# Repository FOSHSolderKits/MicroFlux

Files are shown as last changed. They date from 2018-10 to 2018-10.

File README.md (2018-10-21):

# MicroFlux
Like a microphone, but for magnetic flux.

Based on the idea of the [Elektrosluch](https://store.lom.audio/products/elektrosluch-3?variant=4542168268832).



## Explanation
The explanation of how the circuit works, is annotated in the [schematic](https://github.com/FOSHSolderKits/MicroFlux/blob/master/img/MicroFlux.pdf).

## Pictures
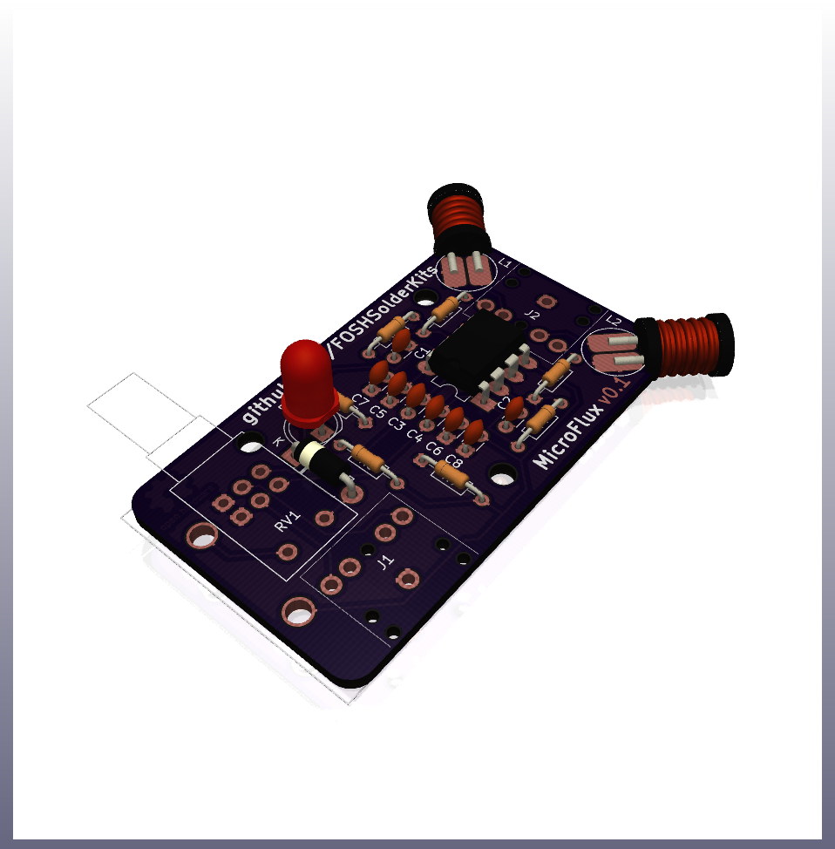
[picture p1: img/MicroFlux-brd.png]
3D render


board plot

schematic plot

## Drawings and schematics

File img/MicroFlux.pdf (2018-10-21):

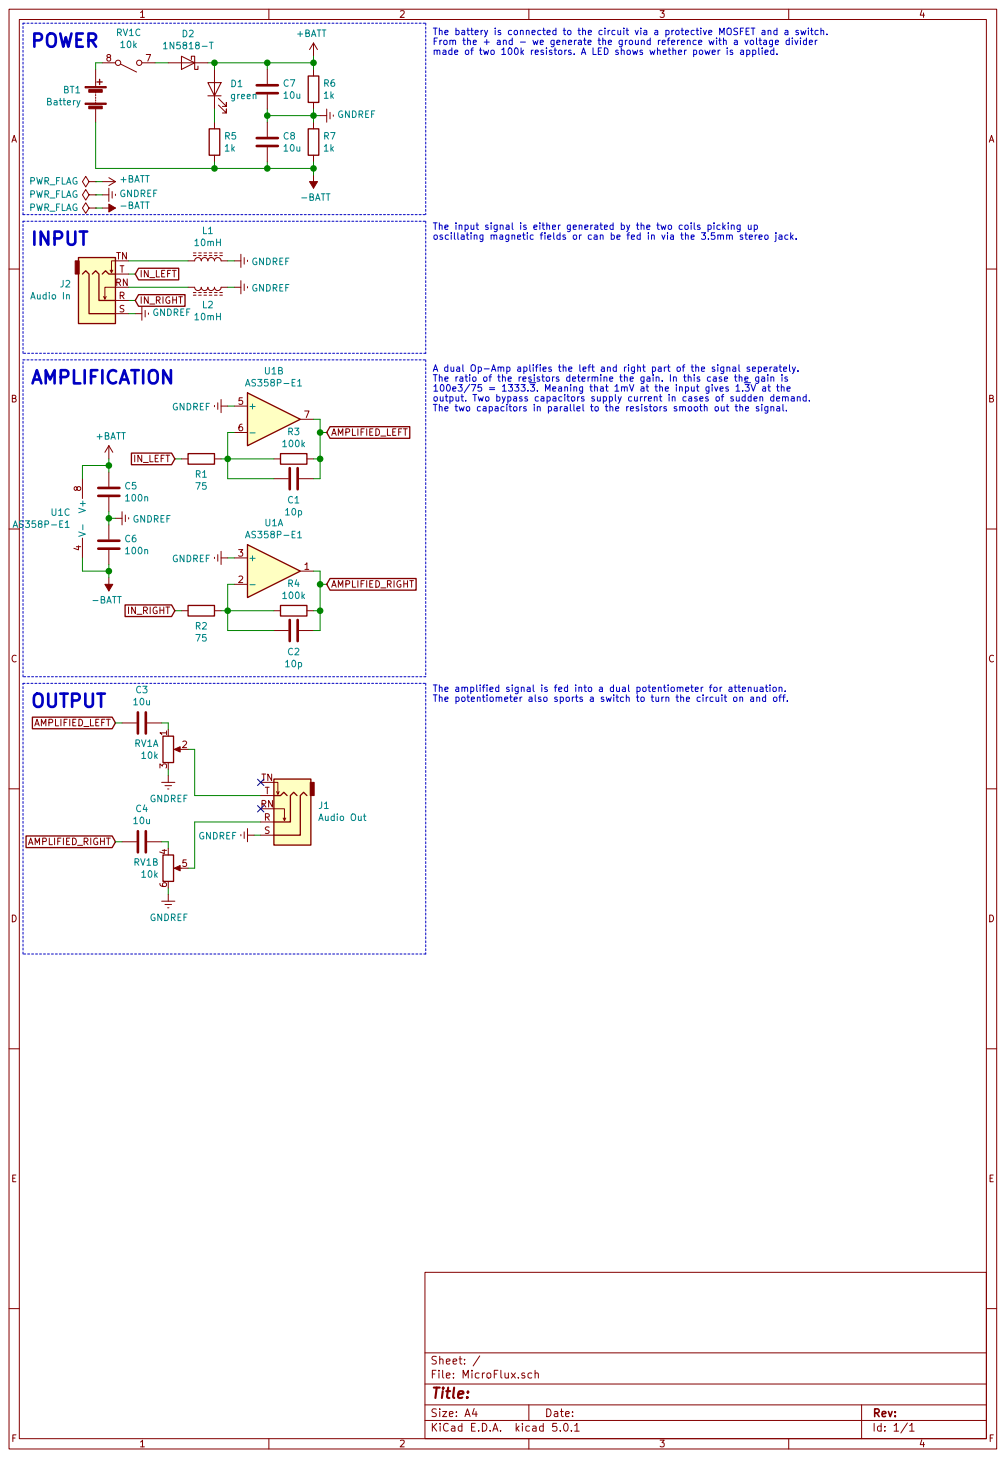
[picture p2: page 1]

The battery is connected to the circuit via a protective MOSFET and a switch.
From the + and - we generate the ground reference with a voltage divider
made of two 100k resistors. A LED shows whether power is applied.

The input signal is either generated by the two coils picking up

oscillating magnetic fields or can be fed in via the 3.5mm stereo jack. GNDREF GNDREF

The ratio of the resistors determine the gain. In this case the gain is
100e3/75 = 1333.3. Meaning that 1mV at the input gives 1.3V at the
output. Two bypass capacitors supply current in cases of sudden demand.
The two capacitors in parallel to the resistors smooth out the signal.

The amplified signal is fed into a dual potentiometer for attenuation.

Id: 1/1 Title: File: MicroFlux.sch Sheet: /

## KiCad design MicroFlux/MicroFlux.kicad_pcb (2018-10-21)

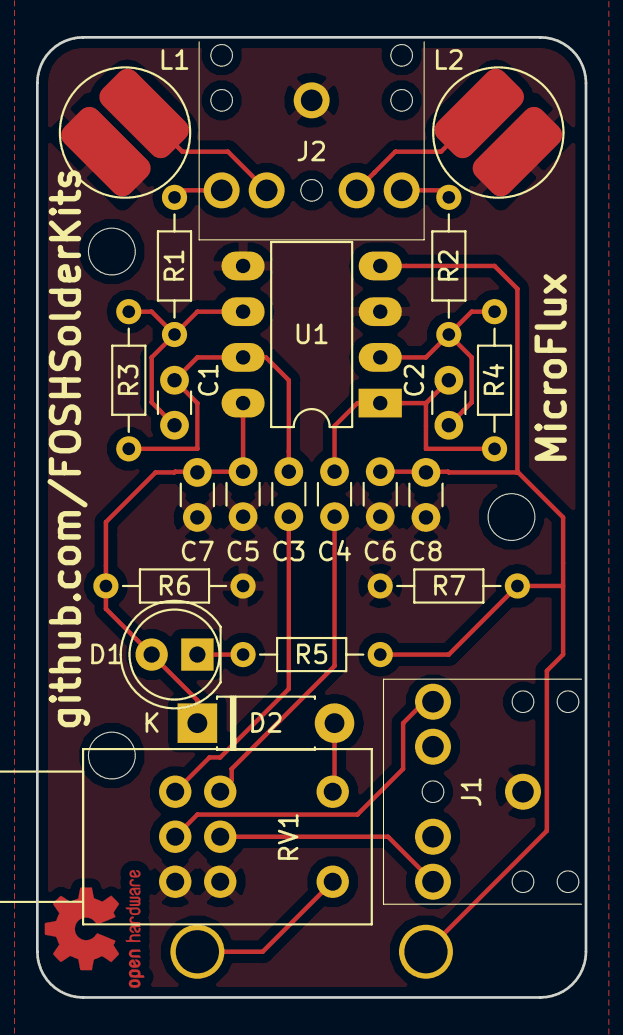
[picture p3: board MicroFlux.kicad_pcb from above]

Board: 2 copper layers, 30.5 x 53.3 mm, 24 parts (1 on the bottom side), 18 nets.

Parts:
BT1: Battery; BatteryHolder_Eagle_12BH611-GR
C1, C2: 10p; C_Disc_D3.0mm_W1.6mm_P2.50mm
C3, C4, C7, C8: 10u; C_Disc_D3.0mm_W1.6mm_P2.50mm
C5, C6: 100n; C_Disc_D3.0mm_W1.6mm_P2.50mm
D1: green; LED_D5.0mm
D2: 1N5818-T; D_DO-41_SOD81_P7.62mm_Horizontal
J1: Audio Out; 3F07
J2: Audio In; 3F07
L1, L2: 10mH; L_Radial_D7.0mm_P3.00mm
R1, R2: 75; R_Axial_DIN0204_L3.6mm_D1.6mm_P7.62mm_Horizontal
R3, R4: 100k; R_Axial_DIN0204_L3.6mm_D1.6mm_P7.62mm_Horizontal
R5, R6, R7: 1k; R_Axial_DIN0204_L3.6mm_D1.6mm_P7.62mm_Horizontal
RV1: 10k; Potentiometer_Alps_RK097_Dual_Horizontal_Switch
U1: AS358P-E1; DIP-8_W7.62mm_LongPads

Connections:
+BATT: C5.1, C7.1, D1.2, D2.1, R6.1, U1.8
-BATT: BT1.2, C6.2, C8.2, R5.2, R7.2, U1.4
AMPLIFIED_LEFT: C1.1, C3.2, R3.1, U1.7
AMPLIFIED_RIGHT: C2.1, C4.2, R4.1, U1.1
GNDREF: C5.2, C6.1, C7.2, C8.1, J1.S, J2.S, L1.1, L2.1, R6.2, R7.1, RV1.3, RV1.6, U1.3, U1.5
IN_LEFT: J2.T, R1.2
IN_RIGHT: J2.R, R2.2
unnamed: BT1.1, RV1.8
unnamed: C1.2, R1.1, R3.2, U1.6
unnamed: C2.2, R2.1, R4.2, U1.2
unnamed: C3.1, RV1.1
unnamed: C4.1, RV1.4
unnamed: D1.1, R5.1
unnamed: D2.2, RV1.7
unnamed: J1.R, RV1.5
unnamed: J1.T, RV1.2
unnamed: J2.RN, L2.2
unnamed: J2.TN, L1.2

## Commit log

2018-10-18 DRC and List Unconnected passes successfully
    [MicroFlux.kicad_pcb, MicroFlux.sch]
2018-10-18 betterplace an route
    [MicroFlux.kicad_pcb, MicroFlux.sch]
2018-10-18 schematic plot
    [MicroFlux.sch]
2018-10-18 added gerber exported files and zip file
    [MicroFlux-B.Cu.gbr, MicroFlux-B.Fab.gbr, MicroFlux-B.Mask.gbr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]
2018-10-18 restructured directories
    [MicroFlux.kicad_pcb, MicroFlux.sch]
2018-10-18 added logos on board
    [MicroFlux-B.Cu.gbr, MicroFlux-B.Fab.gbr, MicroFlux-B.Mask.gbr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]
2018-10-19 assigned MPNs
    [MicroFlux-B.Cu.gbr, MicroFlux-B.Fab.gbr, MicroFlux-B.Mask.gbr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]
2018-10-19 exported CSV
    [MicroFlux.csv]
2018-10-19 assigned MPN to OP Amp
    [MicroFlux.csv, MicroFlux.sch]
2018-10-21 added version information and locked logos on board
    [MicroFlux-B.Cu.gbr, MicroFlux-B.Fab.gbr, MicroFlux-B.Mask.gbr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]
2018-10-21 ignore gerber and zip files
    [MicroFlux-B.Cu.gbr, MicroFlux-B.Fab.gbr, MicroFlux-B.Mask.gbr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]
